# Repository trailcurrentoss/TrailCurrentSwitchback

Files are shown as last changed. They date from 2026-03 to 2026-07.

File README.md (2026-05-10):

# TrailCurrent Switchback

CAN-controlled 8-channel relay module for the TrailCurrent ecosystem, built on the [Waveshare ESP32-S3-ETH-8DI-8RO-C](https://www.waveshare.com/wiki/ESP32-S3-ETH-8DI-8RO-C).

## Hardware

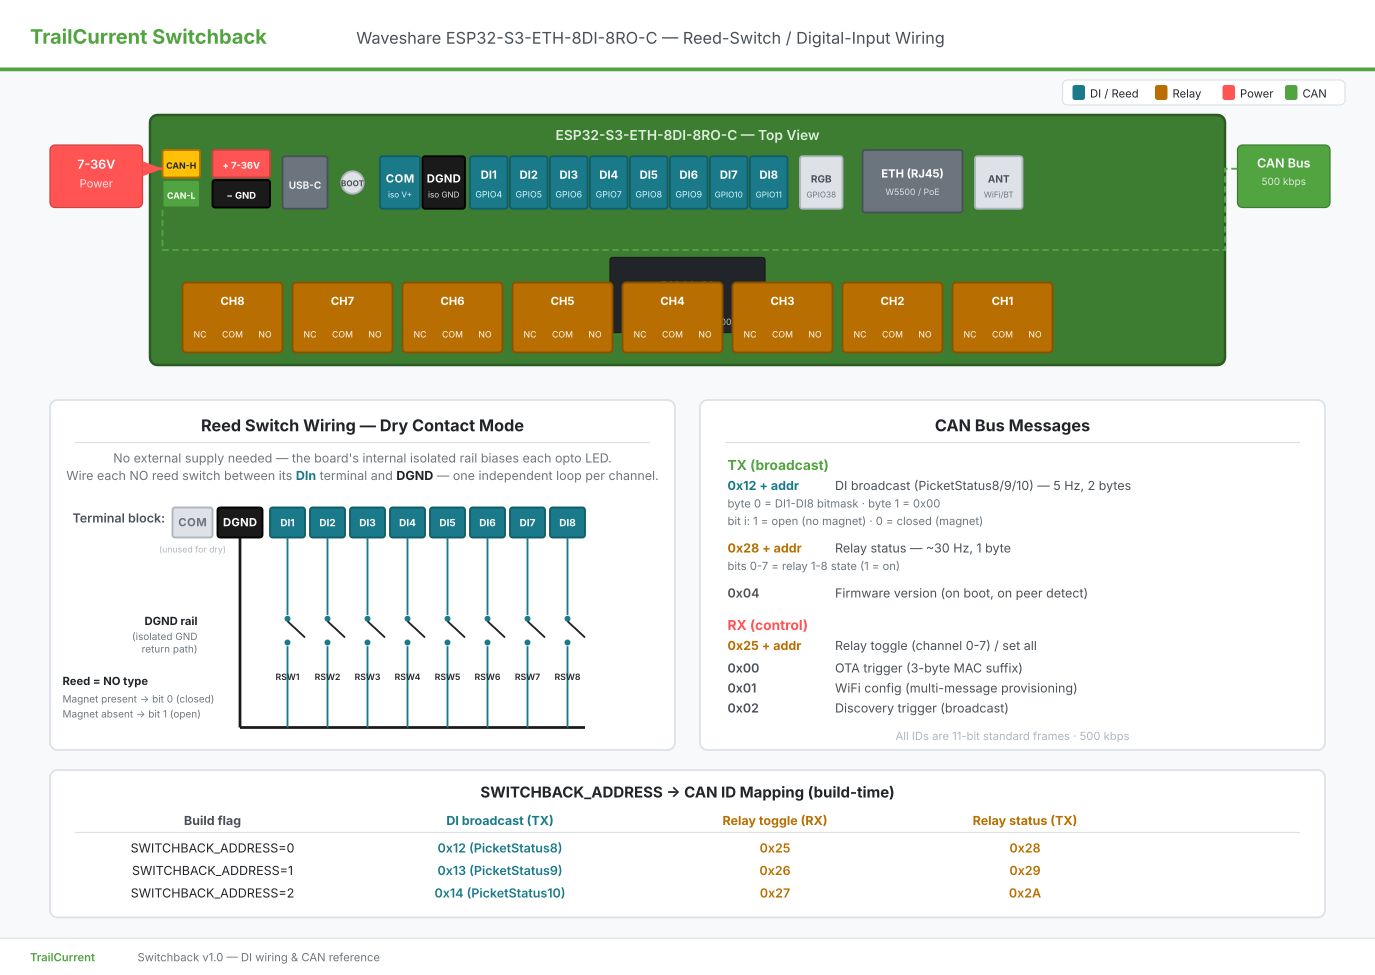
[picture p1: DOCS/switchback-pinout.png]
Switchback pinout and reed switch wiring


For a full design overview see [DOCS/Requirements/high-level-requirements.md](DOCS/Requirements/high-level-requirements.md).

The Waveshare ESP32-S3-ETH-8DI-8RO-C provides:

- **ESP32-S3** dual-core LX7 @ 240 MHz with WiFi and BLE
- **8 relay channels** (1NO/1NC each), rated 10A @ 250V AC / 10A @ 30V DC, via TCA9554PWR I2C I/O expander
- **8 digital inputs** (optocoupler isolated)
- **CAN bus** with onboard transceiver and 120 ohm termination jumper
- **Ethernet** (W5500 via SPI, 10/100 Mbps)
- **7-36V DC** input (or 5V via USB-C)
- **RTC** (PCF85063ATL) with battery backup header
- **SD card** slot (MMC 1-bit mode)
- DIN-rail mount enclosure

## Firmware

### Pin Assignments

Relays are controlled via TCA9554PWR I2C I/O expander (address 0x20) on I2C SDA=GPIO42, SCL=GPIO41.

| Function | Pin / Address |
|---|---|
| Relay 1-8  | TCA9554 P0-P7 (I2C 0x20) |
| DI 1-8 | GPIO 4-11 |
| CAN TX | GPIO 17 |
| CAN RX | GPIO 18 |
| Buzzer | GPIO 46 |
| RGB LED | GPIO 38 |
| ETH MOSI | GPIO 13 |
| ETH MISO | GPIO 14 |
| ETH SCLK | GPIO 15 |
| ETH CS | GPIO 16 |

### CAN Protocol

CAN bus runs at **500 kbps** in no-ACK mode.

| CAN ID | Direction | Description |
|---|---|---|
| `0x00` | RX | **OTA trigger** — 3-byte payload (MAC bytes 3-5) targets a specific device |
| `0x01` | RX | **WiFi config** — multi-message chunked protocol to provision SSID and password |
| `0x12 + addr` | TX | **Digital input broadcast** — 2-byte Picket-format frame (byte 0 = DI1-DI8 bitmask, byte 1 = 0x00), 5 Hz. Identical wire format to `PicketStatus0..7`, so Headwaters decodes it through the same path. |
| `0x25 + addr` | RX | **Relay toggle** — toggle a single relay (channel 0-7) or set all relays (channel >= 8, byte 2 = on/off) |
| `0x28 + addr` | TX | **Relay status broadcast** — 1-byte bitmask (bits 0-7 = relay states), sent at ~30 Hz |

Up to 3 Switchback modules can share the same CAN bus. CAN IDs are offset by the `SWITCHBACK_ADDRESS` build flag:

| Base ID | Addr 0 | Addr 1 | Addr 2 | Description |
|---|---|---|---|---|
| 0x12 | 0x12 | 0x13 | 0x14 | Digital input broadcast (TX) — `PicketStatus8/9/10` |
| 0x25 | 0x25 | 0x26 | 0x27 | Relay toggle (RX) |
| 0x28 | 0x28 | 0x29 | 0x2A | Relay status broadcast (TX) |

The DI broadcast (CAN ID `0x12 + addr`) reuses the **Picket** message format byte-for-byte: byte 0 carries DI1-DI8 (`1` = open / no current through optocoupler, `0` = closed); byte 1 is always `0x00` (Picket uses it for inputs 9-12, which Switchback hardware doesn't expose). Inputs are debounced for 50 ms and the frame is sent at 5 Hz, matching Picket exactly. For dry-contact wiring, connect each NO reed switch between its `DIn` terminal and `DGND` — the board's internal isolated rail biases the optocoupler LEDs, so no external supply is needed. See [DOCS/switchback-pinout.png](DOCS/switchback-pinout.png) for the full wiring diagram.

### WiFi Provisioning over CAN

WiFi credentials can be sent to the device over the CAN bus using a multi-message protocol on CAN ID `0x01`:

1. **Start** (type `0x01`) — declares SSID length, password length, chunk counts, and checksum
2. **SSID chunks** (type `0x02`) — up to 6 bytes per message, indexed
3. **Password chunks** (type `0x03`) — up to 6 bytes per message, indexed
4. **End** (type `0x04`) — verifies XOR checksum and saves credentials to NVS

A 5-second timeout resets the state if the sequence is not completed.

### OTA Updates

The firmware supports over-the-air updates via WiFi. An OTA trigger message on CAN ID `0x00` with the device's MAC address (bytes 3-5) puts the device into OTA mode. The flash partition table supports dual-OTA (app0/app1) for safe rollback.

Always use the app-only binary (`switchback_addr{N}.bin`) for OTA, never the merged binary. The merged binary starts with the bootloader, not an app header, and would fail the `esp_ota_end` validation.

```bash
curl -X POST http://esp32-XXYYZZ.local/ota --data-binary @build/switchback_addr0.bin
```

## Building

### Prerequisites

- [ESP-IDF](https://docs.espressif.com/projects/esp-idf/en/stable/esp32s3/get-started/) v5.x

### Build and Flash

```bash
idf.py set-target esp32s3
idf.py build
idf.py -p /dev/ttyACM0 flash monitor
```

### Multi-Instance Addressing

Up to 3 Switchback modules can share the same CAN bus. Each module is built with a unique address:

```bash
idf.py build                        # Address 0 (default)
idf.py build -DSWITCHBACK_ADDRESS=1  # Address 1
idf.py build -DSWITCHBACK_ADDRESS=2  # Address 2
```

#### Building All Variants

Use `build-all.sh` to build all 3 address variants in a single run:

```bash
./build-all.sh
```

This produces two binaries per address — one for OTA updates, one for the web flasher:

| File | Contents | Used By |
|---|---|---|
| `build/switchback_addr{N}.bin` | Application image only | Headwaters OTA (`deploy.sh`, `ota.js`), direct `curl` uploads |
| `build/switchback_addr{N}_merged.bin` | Bootloader + partition table + OTA data + application | Web flasher (full flash at 0x0) |

The two binary types exist because OTA and the web flasher write to different targets. Headwaters OTA sends the binary to the device's `/ota` HTTP endpoint, which calls `esp_ota_write` to write it to a single app partition. That function validates the image as an application — a merged binary starts with the bootloader instead of an app header, so it would fail validation. The web flasher writes the entire flash contents starting at offset 0x0, so it needs all partitions combined into one file.

#### Creating a GitHub Release

After building all variants, attach all 6 binaries (3 app-only + 3 merged) as release assets:

```bash
git tag -a v1.0.0 -m "Firmware release v1.0.0"
git push origin v1.0.0

gh release create v1.0.0 \
  build/switchback_addr0.bin \
  build/switchback_addr1.bin \
  build/switchback_addr2.bin \
  build/switchback_addr0_merged.bin \
  build/switchback_addr1_merged.bin \
  build/switchback_addr2_merged.bin \
  --repo trailcurrentoss/TrailCurrentSwitchback \
  --title "v1.0.0" \
  --notes "Firmware release v1.0.0"
```

Both the Headwaters deployment system and the web flasher pull from GitHub releases. The web flasher matches `_merged.bin` files by name for full-flash use. The Headwaters deployment system (`fetch-firmware.sh`) downloads the app-only `switchback_addr{N}.bin` files for OTA delivery.

## Project Structure

```
TrailCurrentSwitchback/
├── main/
│   ├── main.c              # Entry point — init and CAN task
│   ├── board.h             # Pin definitions for ESP32-S3-ETH-8DI-8RO-C
│   ├── relay.h / relay.c   # TCA9554 I2C relay driver (8 channels)
│   ├── can_handler.h / .c  # CAN protocol and message handling
│   ├── wifi_config.h / .c  # WiFi credential storage and CAN provisioning
│   ├── discovery.h / .c    # mDNS self-discovery and Headwaters registration
│   └── ota.h / ota.c       # OTA firmware updates via WiFi
├── CMakeLists.txt          # Top-level ESP-IDF project file
├── partitions.csv          # Custom flash partition table (dual OTA)
├── build-all.sh            # Build all 3 address variants (addr 0-2)
└── sdkconfig.defaults      # Default SDK configuration
```

## License

See [LICENSE](LICENSE) for details.

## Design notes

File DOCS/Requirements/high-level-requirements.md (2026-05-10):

# High-Level Design (HLD) Document

## 1. Project Overview

**Project Title:** Switchback Module

**Description:** A microcontroller-based system that controls 8 high-current relay outputs over a CAN bus and reports their state back to the network. Reused as a slimmed-down [Picket](../../../TrailCurrentPicket/README.md) replacement when 8 reed-switch / digital inputs are sufficient — the same physical board exposes 8 optocoupler-isolated digital inputs that broadcast door / cabinet status in the existing PicketStatus wire format.

**Objective:**
To design and implement a reliable, industrial-grade, CAN-controlled relay module for the TrailCurrent vehicle platform that can also subsume the Picket door-sensing role at locations where 8 inputs cover the wiring need, eliminating a separate node, its enclosure, its CAN address, and its quiescent power draw.

---

## 2. Microcontroller Selection

**Selected Microcontroller:**
**ESP32-S3** ([Waveshare ESP32-S3-ETH-8DI-8RO-C](https://www.waveshare.com/wiki/ESP32-S3-ETH-8DI-8RO-C))
[Datasheet](https://www.espressif.com/sites/default/files/documentation/esp32-s3_datasheet_en.pdf)

**Rationale for Selection:**
- Off-the-shelf industrial DIN-rail board with **8 onboard relays** (10 A @ 250 V AC / 30 V DC) driven through a TCA9554PWR I²C expander. No relay driver circuit to design.
- **8 digital inputs with bidirectional optocoupler isolation** and onboard isolated supply rail — supports both dry-contact (reed switches, buttons) and wet-contact (5–36 V sensors) wiring without external components.
- Onboard isolated CAN transceiver, W5500 Ethernet, RTC with battery backup, SD slot, RGB LED, buzzer.
- 7–36 V wide-input buck converter (or 5 V via USB-C) — directly compatible with vehicle 12 V / 24 V systems.
- DIN-rail enclosure ships with the board.
- Same ESP-IDF / ESP32-S3 toolchain shared across Picket, Solstice, and other TrailCurrent modules.

---

## 3. System Requirements

### 3.1 Functional Requirements

| Requirement | Description |
|---|---|
| Relay Control | Receive CAN commands to toggle individual relays (channel 0–7) or set all relays on/off. |
| Relay Status Reporting | Broadcast the current 8-bit relay state on CAN at ~30 Hz. |
| Digital Input Sensing | Read 8 optocoupler-isolated inputs and broadcast their debounced state on CAN at 5 Hz in PicketStatus wire format. |
| Multi-Module Addressing | Up to 3 modules per CAN bus. CAN IDs offset by `SWITCHBACK_ADDRESS` build flag (0–2). |
| OTA Updates | Accept firmware updates over WiFi triggered via CAN ID 0x00. Dual-OTA partition layout for safe rollback. |
| Auto-Discovery | Respond to CAN-broadcast discovery triggers by joining WiFi and advertising over mDNS for Headwaters to register. |
| Bus-Off Recovery | Detect TWAI bus-off, initiate recovery, and resume TX automatically when the bus is healthy. |
| No-Peer Probe Mode | Slow down TX to 0.5 Hz when no CAN peers are detected; resume normal cadence on first ACK / RX. |

### 3.2 Non-Functional Requirements

| Requirement | Description |
|---|---|
| Reliability | System must operate continuously without disruption indefinitely for solar / off-grid installs. |
| CAN Bus Data Usage | Combined relay status (30 Hz, 1 byte) + DI broadcast (5 Hz, 2 bytes) ≈ 47 frame-bytes/s per module — negligible on a 500 kbps bus. |
| Environmental Tolerance | Operate within typical industrial ranges (board-rated -20 °C to +70 °C). |
| Galvanic Isolation | All relay-side and input-side connections must remain optically / power-isolated from the MCU rail. |
| Cost | Use the off-the-shelf board as-is; no custom PCB required. |

---

## 4. System Architecture Overview

### 4.0 External Wiring Reference

Switchback pinout and reed switch wiring

The diagram shows every screw-terminal and connector exposed on the [Waveshare ESP32-S3-ETH-8DI-8RO-C](https://www.waveshare.com/wiki/ESP32-S3-ETH-8DI-8RO-C), the dry-contact reed-switch wiring (no external supply needed — the board's onboard isolated rail provides loop current), and the CAN ID layout for all three `SWITCHBACK_ADDRESS` build values.

### 4.1 Hardware Components

| Component | Description |
|---|---|
| ESP32-S3 (Waveshare ESP32-S3-ETH-8DI-8RO-C) | Main microcontroller with onboard CAN, Ethernet, 8 relays, 8 DIs |
| TCA9554PWR I²C I/O Expander | Drives the 8 relay coils (address 0x20, on internal I²C bus SDA=GPIO42 / SCL=GPIO41) |
| Onboard Optocouplers (input side) | Bidirectional isolation for the 8 digital inputs |
| W5500 Ethernet Controller | SPI-attached, currently unused by firmware (reserved for future expansion) |
| PCF85063ATL RTC | Battery-backed real-time clock (currently unused) |
| Reed Switches / Buttons / Sensors | External — wired to DI terminals via dry- or wet-contact configuration |

### 4.2 Software Components

| Component | Description |
|---|---|
| Main Application (`main.c`) | Boot, peripheral init, task spawning |
| Relay Driver (`relay.c`) | TCA9554 I²C bring-up, per-channel toggle, get-states bitmask |
| CAN Handler (`can_handler.c`) | TWAI driver, RX dispatch, relay-status TX (~30 Hz), DI debounce + DI broadcast (5 Hz) |
| WiFi Config (`wifi_config.c`) | NVS-stored credentials and CAN-based provisioning protocol on ID 0x01 |
| OTA (`ota.c`) | HTTP-based OTA update flow, triggered by CAN ID 0x00 with this module's MAC suffix |
| Discovery (`discovery.c`) | mDNS advertisement + Headwaters confirm-handshake on a one-at-a-time CAN-triggered window |
| CAN Common (`can_common.h`, shared library) | Bus init, alert mask, version-broadcast helper — same module used across all TrailCurrent firmware |

### 4.3 Dual-Role Operation

A single Switchback firmware build runs both functions concurrently. The two roles are independent:

| Role | CAN ID (per `SWITCHBACK_ADDRESS`) | Cadence | Source of Truth |
|---|---|---|---|
| Relay status TX | 0x28 / 0x29 / 0x2A | ~30 Hz | TCA9554 output register cache |
| Relay toggle RX | 0x25 / 0x26 / 0x27 | event-driven | Headwaters / dashboards |
| DI broadcast TX | **0x12 / 0x13 / 0x14** | 5 Hz | 50 ms-debounced GPIO read |

The DI side is a byte-for-byte clone of the Picket message format (1 = open, 0 = closed; debounce window, cadence, and signal layout all identical). It extends the Picket address pool — the canonical DBC name for the new IDs is `PicketStatus8`, `PicketStatus9`, `PicketStatus10`.

---

## 5. Communication Protocol

- **CAN Bus:** 500 kbps, no-ACK mode (TWAI driver in normal mode).
- **Data Format:** See [Switchback README — CAN Protocol](../../README.md#can-protocol) and the canonical [TrailCurrent.dbc](../../../TrailCurrentDocumentation/TrailCurrent.dbc).
- **Transmission Frequency:**
  - Relay status: ~30 Hz (33 ms period) — fast enough that downstream UIs feel responsive after a toggle.
  - DI broadcast: 5 Hz (200 ms period) — matches Picket exactly so the same Headwaters consumer code decodes both.
- **Probe Backoff:** When no peers are observed, both TX paths slow to 0.5 Hz to avoid spamming an empty bus, resuming full rate on first TX_SUCCESS or RX_DATA.

---

## 6. Power Management Strategy

- **Input:** 7–36 V DC via screw terminal (vehicle 12 V or 24 V), or 5 V via USB-C for bench work.
- **Onboard Power:** Built-in MP1605GTF-Z buck converter feeds the ESP32-S3 and isolated rails.
- **Quiescent Draw:** Dominated by the W5500, ESP32 WiFi/BLE radios (idle), and the optocoupler bias current. Significantly lower system draw than running a Switchback + Picket pair at the same location.

---

## 7. Development Tools and Environment

| Tool | Description |
|---|---|
| ESP-IDF | Development framework (v5.x) |
| VS Code | Development IDE |
| Git / GitHub | Source control, releases (binaries attached to tagged releases) |
| TrailCurrentCANLibrary | Shared CAN init / version-broadcast component, pulled in via `EXTRA_COMPONENT_DIRS` |
| Documentation Tools | Markdown, DBC for the canonical CAN signal definitions |

---

## 8. Testing and Validation

| Test Type | Description |
|---|---|
| Unit | Per-module — relay driver, DI read path, CAN message parsing |
| Integration | Full firmware on hardware: relay toggle round-trip, DI debounce timing, dual-role TX coexistence |
| Field | Multi-module bus with mixed Picket + Switchback nodes; verify Headwaters decodes 0x0A–0x14 uniformly |
| OTA | Push a new build, verify dual-OTA rollback path on a deliberately corrupt image |

---

## 9. Future Enhancements

- Use the onboard W5500 Ethernet for CAN-over-Ethernet bridging or a direct HTTP control API.
- Wire the RTC to provide a network-independent timestamp for input transitions.
- Add SD-card logging of input-edge events for forensic / diagnostic recall.
- Per-channel relay current sensing (would require an external module — not on this board).

---

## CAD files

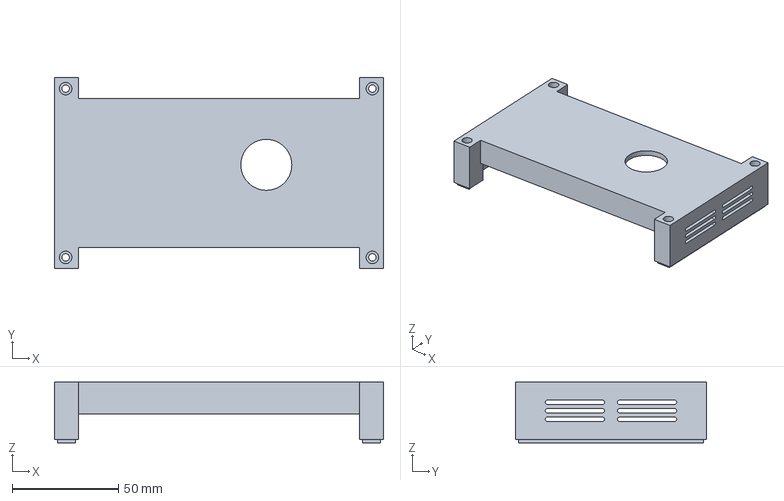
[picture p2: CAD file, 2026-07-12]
CAD/WaveshareCoverWithBorealisAndBearing.FCStd
155.0 x 90.0 x 28.6 mm

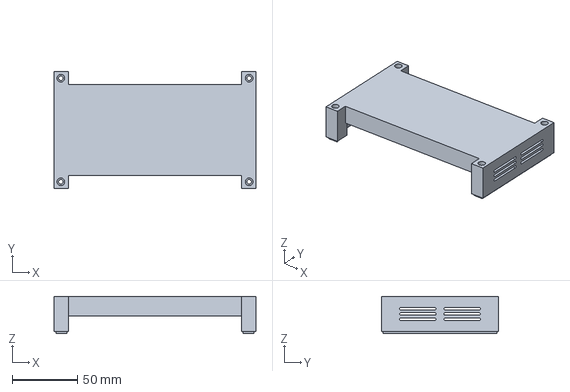
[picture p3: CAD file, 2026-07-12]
CAD/WaveshareCover.FCStd
155.0 x 90.0 x 28.6 mm

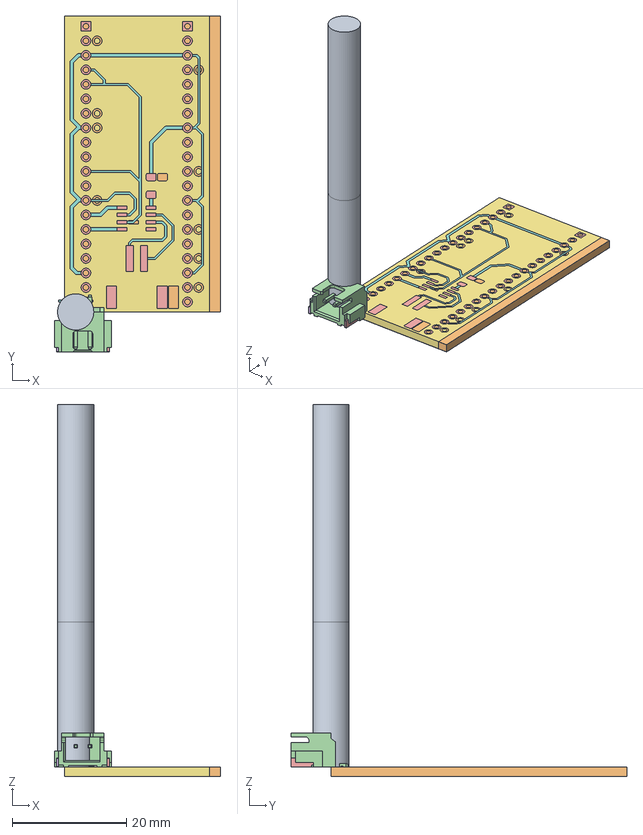
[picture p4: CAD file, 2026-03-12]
CAD/TrailCurrentSwitchbackPcb.FCStd
29.2 x 58.8 x 65.1 mm
Model-TrailCurrentSwitchback
Model-TrailCurrentSwitchback001
BODY-SO
LEAD-D0008A
LEAD-D0008A001
LEAD-D0008A002
LEAD-D0008A003
LEAD-D0008A004
LEAD-D0008A005
LEAD-D0008A006
LEAD-D0008A007
SxB-XH-SM4-TB
SxB-XH-SM4-TB001
SxB-XH-SM4-TB002
Pcb_5bca
topTracks_5bca
SpeTool O Flute 1/4"
Stock009
Stock010
1mm Drill
topPads_5bca
botPads_5bca
botZones_5bca

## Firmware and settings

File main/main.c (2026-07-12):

#include "board.h"
#include "relay.h"
#include "can_handler.h"
#include "wifi_config.h"
#include "discovery.h"
#include "ota.h"
#include "esp_log.h"
#include "driver/gpio.h"
#include "freertos/FreeRTOS.h"
#include "freertos/task.h"
#ifdef SWITCHBACK_VARIANT_GNSS
#include "gnss.h"
#endif
#ifdef SWITCHBACK_VARIANT_SCD41
#include "sensors.h"
#endif

#ifndef SWITCHBACK_ADDRESS
#define SWITCHBACK_ADDRESS 0
#endif

static const char *TAG = "main";

#ifdef SWITCHBACK_VARIANT_GNSS
// Bridge from the gnss RX task straight into the CAN handler's snapshot.
// Fires once per NMEA sentence (RMC + GGA at 1 Hz) — no polling.
static void on_gnss_update(const gnss_data_t *data)
{
    can_handler_publish_gnss(data);
}
#endif  // SWITCHBACK_VARIANT_GNSS

#ifdef SWITCHBACK_VARIANT_SCD41
// SCD41 produces a fresh sample every 5 s in periodic mode. Poll a bit
// faster than that so we don't drift and always publish the newest fix
// as soon as data-ready flips.
#define SCD41_POLL_MS  2000

// Track the latest SCD41 fields so the SGP40 measurement can compensate for
// humidity/temp even on ticks where SCD41 didn't produce fresh data.
static float s_last_temp_c = 25.0f;
static float s_last_humidity = -1.0f;

static void scd41_poll_task(void *arg)
{
    while (1) {
        scd41_data_t d = scd41_read();
        if (d.valid) {
            ESP_LOGI("main", "SCD41: %.1f°C / RH %.1f%% / CO2 %u ppm",
                     d.temperature_c, d.humidity, d.co2_ppm);
            s_last_temp_c = d.temperature_c;
            s_last_humidity = d.humidity;
            can_handler_publish_env(&d);
        }

        // SGP40 needs humidity + temperature for compensation; pass the last
        // good SCD41 pair, or use the datasheet defaults (humidity=-1) if
        // SCD41 hasn't published yet.
        sgp40_data_t sgp = sgp40_measure(s_last_humidity, s_last_temp_c);
        if (sgp.valid) {
            ESP_LOGI("main", "SGP40: VOC raw %u index %u",
                     sgp.voc_raw, sgp.voc_index);
            can_handler_publish_voc(&sgp);
        }

        // SEN0466 CO — active-mode sensor updates ~1 Hz internally, so a
        // read each poll cycle always gives the freshest number.
        co_data_t co = co_sen0466_read();
        if (co.valid) {
            ESP_LOGI("main", "SEN0466: CO %.1f ppm", co.ppm);
            can_handler_publish_co(&co);
        }

        vTaskDelay(pdMS_TO_TICKS(SCD41_POLL_MS));
    }
}
#endif  // SWITCHBACK_VARIANT_SCD41

static void init_digital_inputs(void)
{
    gpio_config_t io_conf = {
        .mode = GPIO_MODE_INPUT,
        .pull_up_en = GPIO_PULLUP_ENABLE,
        .pull_down_en = GPIO_PULLDOWN_DISABLE,
        .intr_type = GPIO_INTR_DISABLE,
    };

    for (int i = 0; i < NUM_DIN; i++) {
        io_conf.pin_bit_mask = 1ULL << DIN_PINS[i];
        gpio_config(&io_conf);
    }

    ESP_LOGI(TAG, "8 digital inputs initialized");
}

void app_main(void)
{
    // Quiet the GNSS + RX chatter so the sensor + relay output stays readable.
    // Errors still surface. Raise back to INFO temporarily if debugging GNSS.
    esp_log_level_set("gnss", ESP_LOG_WARN);

    ESP_LOGI(TAG, "=== TrailCurrent Switchback ===");
    ESP_LOGI(TAG, "CAN-Controlled 8-Channel Relay Module");
    ESP_LOGI(TAG, "Board: Waveshare ESP32-S3-ETH-8DI-8RO-C");

    // Initialize NVS and load WiFi credentials
    ESP_ERROR_CHECK(wifi_config_init());

    char ssid[33] = {0};
    char password[64] = {0};
    if (wifi_config_load(ssid, sizeof(ssid), password, sizeof(password))) {
        ESP_LOGI(TAG, "WiFi credentials loaded from NVS");
    } else {
        ESP_LOGI(TAG, "No WiFi credentials — OTA disabled until provisioned via CAN");
    }

    // Initialize relay outputs via TCA9554 I2C expander
    ESP_ERROR_CHECK(relay_init());

    // Initialize digital inputs
    init_digital_inputs();

    // Initialize discovery and OTA (must be after wifi_config_init)
    discovery_init();
    ota_init();

#if defined(SWITCHBACK_VARIANT_AFTLINE)
    ESP_LOGI(TAG, "Switchback+Aftline addr=%d (Toggle 0x%02X, Status 0x%02X, TrailerStatus 0x3A)",
             SWITCHBACK_ADDRESS,
             CAN_ID_TOGGLE_BASE + SWITCHBACK_ADDRESS,
             CAN_ID_STATUS_BASE + SWITCHBACK_ADDRESS);
#elif defined(SWITCHBACK_VARIANT_PICKET) && defined(SWITCHBACK_VARIANT_GNSS)
    ESP_LOGI(TAG, "Switchback+Picket+GNSS+Env+Safety addr=%d (Toggle 0x%02X, Status 0x%02X, Input 0x%02X, GNSS 0x06-0x09, Env 0x1F, Safety 0x20)",
             SWITCHBACK_ADDRESS,
             CAN_ID_TOGGLE_BASE + SWITCHBACK_ADDRESS,
             CAN_ID_STATUS_BASE + SWITCHBACK_ADDRESS,
             CAN_ID_INPUT_BASE + SWITCHBACK_ADDRESS);
#elif defined(SWITCHBACK_VARIANT_PICKET)
    ESP_LOGI(TAG, "Switchback+Picket addr=%d (Toggle 0x%02X, Status 0x%02X, Input 0x%02X)",
             SWITCHBACK_ADDRESS,
             CAN_ID_TOGGLE_BASE + SWITCHBACK_ADDRESS,
             CAN_ID_STATUS_BASE + SWITCHBACK_ADDRESS,
             CAN_ID_INPUT_BASE + SWITCHBACK_ADDRESS);
#else
    ESP_LOGI(TAG, "Switchback (base) addr=%d (Toggle 0x%02X, Status 0x%02X, no DI broadcast)",
             SWITCHBACK_ADDRESS,
             CAN_ID_TOGGLE_BASE + SWITCHBACK_ADDRESS,
             CAN_ID_STATUS_BASE + SWITCHBACK_ADDRESS);
#endif

    // Initialize CAN bus
    ESP_ERROR_CHECK(can_handler_init());

    // Run CAN handler on a dedicated task
    xTaskCreatePinnedToCore(can_handler_task, "can_task", 4096, NULL, 5, NULL, 1);

#ifdef SWITCHBACK_VARIANT_GNSS
    // DFRobot Gravity GNSS module in UART mode — 9600 baud NMEA. Header pin
    // wiring: D/T (module TX) → ESP RX; C/R (module RX) → ESP TX. UART1 via
    // the GPIO matrix keeps UART0/console untouched.
    ESP_ERROR_CHECK(gnss_init(SWITCHBACK_GNSS_UART_NUM,
                              SWITCHBACK_GNSS_UART_TX,
                              SWITCHBACK_GNSS_UART_RX,
                              SWITCHBACK_GNSS_BAUD,
                              on_gnss_update));
#endif

#ifdef SWITCHBACK_VARIANT_SCD41
    // Air-quality sensor bank on the shared I2C bus (same bus as the TCA9554
    // relay expander): SCD41 CO2/T/RH @ 0x62, SGP40 VOC @ 0x59, SEN0466 CO
    // @ 0x74. Attaches whatever's present; missing devices just leave their
    // slice of the CAN broadcast at zero.
    if (sensors_init(relay_get_i2c_bus()) == ESP_OK) {
        scd41_start_periodic();
        co_sen0466_set_active_mode();
        xTaskCreatePinnedToCore(scd41_poll_task, "scd41", 4096, NULL, 3, NULL, 0);
    } else {
        ESP_LOGW(TAG, "Sensor init failed — environmental / safety broadcast disabled");
    }
#endif

    ESP_LOGI(TAG, "=== Setup Complete ===");
}

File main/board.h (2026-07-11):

#pragma once

#include "driver/gpio.h"
#include "driver/i2c_master.h"
#include "driver/twai.h"
#include "driver/uart.h"

// --- Waveshare ESP32-S3-ETH-8DI-8RO-C pin assignments ---

// I2C bus (TCA9554PWR relay expander + PCF85063ATL RTC)
#define BOARD_I2C_SDA_PIN       GPIO_NUM_42
#define BOARD_I2C_SCL_PIN       GPIO_NUM_41
#define BOARD_I2C_FREQ_HZ       100000

// TCA9554PWR I/O expander (8 relay outputs)
#define TCA9554_ADDR            0x20
#define TCA9554_REG_INPUT       0x00
#define TCA9554_REG_OUTPUT      0x01
#define TCA9554_REG_POLARITY    0x02
#define TCA9554_REG_CONFIG      0x03

#define NUM_RELAYS              8

// Digital inputs (optocoupler isolated, active-low)
#define DI1_PIN                 GPIO_NUM_4
#define DI2_PIN                 GPIO_NUM_5
#define DI3_PIN                 GPIO_NUM_6
#define DI4_PIN                 GPIO_NUM_7
#define DI5_PIN                 GPIO_NUM_8
#define DI6_PIN                 GPIO_NUM_9
#define DI7_PIN                 GPIO_NUM_10
#define DI8_PIN                 GPIO_NUM_11

#define NUM_DIN                 8

static const gpio_num_t DIN_PINS[NUM_DIN] = {
    DI1_PIN, DI2_PIN, DI3_PIN, DI4_PIN,
    DI5_PIN, DI6_PIN, DI7_PIN, DI8_PIN
};

// CAN bus (TWAI) — shared with RS485, we use CAN mode
#define CAN_TX_PIN              GPIO_NUM_17
#define CAN_RX_PIN              GPIO_NUM_18

// Buzzer (PWM)
#define BUZZER_PIN              GPIO_NUM_46

// WS2812 RGB LED
#define RGB_LED_PIN             GPIO_NUM_38

// Ethernet (W5500 via SPI)
#define ETH_MOSI_PIN            GPIO_NUM_13
#define ETH_MISO_PIN            GPIO_NUM_14
#define ETH_SCLK_PIN            GPIO_NUM_15
#define ETH_CS_PIN              GPIO_NUM_16
#define ETH_INT_PIN             GPIO_NUM_12
#define ETH_RST_PIN             GPIO_NUM_39

// CAN protocol IDs
#define CAN_ID_OTA              0x00
#define CAN_ID_WIFI_CONFIG      0x01
#define CAN_ID_DISCOVERY_TRIGGER 0x02
#define CAN_ID_TOGGLE_BASE      0x25   // + SWITCHBACK_ADDRESS → 0x25-0x27
#define CAN_ID_STATUS_BASE      0x28   // + SWITCHBACK_ADDRESS → 0x28-0x2A
// Reed-switch / digital-input broadcast — Picket-format frame, 5 Hz.
// Lives in the Picket address pool 0x0A-0x14 (Picket fills 0x0A-0x11; Switchback
// extends with addresses 8-10 at 0x12-0x14). Identical 2-byte wire layout, so any
// PicketStatus consumer decodes Switchback DIs without code changes.
#define CAN_ID_INPUT_BASE       0x12   // + SWITCHBACK_ADDRESS → 0x12-0x14

// Bearing-format GNSS broadcast (picket_gnss variant only). Same wire layout
// as standalone Bearing modules, so any GNSS consumer decodes these without
// changes. Do NOT run a picket_gnss Switchback and a standalone Bearing on
// the same CAN bus — both would broadcast the same IDs.
#define CAN_ID_DATETIME         0x06
#define CAN_ID_SAT_SPEED        0x07
#define CAN_ID_ALTITUDE         0x08
#define CAN_ID_LATLON           0x09

// Environmental broadcast (picket_gnss variant only, when SCD41+SGP40 are
// attached). Same wire layout as standalone Borealis EnvironmentalStatus.
// Don't run a picket_gnss Switchback and a standalone Borealis on the same
// bus — both would broadcast 0x1F / 0x20.
#define CAN_ID_ENVIRONMENTAL    0x1F
#define CAN_ID_SAFETY           0x20

// Alarm bitmask packed into the SafetyStatus frame. Matches Borealis so
// existing dashboards decode it unchanged. LPG bits stay zero because
// Switchback carries no MQ-6 propane sensor.
#define ALARM_FLAG_CO_WARN      0x01
#define ALARM_FLAG_CO_ALARM     0x02
#define ALARM_FLAG_LPG_WARN     0x04
#define ALARM_FLAG_LPG_ALARM    0x08
#define ALARM_FLAG_CO2_WARN     0x10
#define ALARM_FLAG_CO2_ALARM    0x20
#define ALARM_FLAG_VOC_ALARM    0x40

// Thresholds — same values Borealis uses so a single dashboard config works
// across every TrailCurrent module.
#define CO_PPM_WARNING          70
#define CO_PPM_ALARM            200
#define CO2_PPM_WARNING         1500
#define CO2_PPM_ALARM           2500
#define VOC_INDEX_ALARM         400

// CAN baud rate
#define CAN_BAUD_RATE           500  // kbps

// --- picket_gnss variant (SWITCHBACK_VARIANT_GNSS defined) ---
// DFRobot Gravity GNSS (TEL0157) via UART1 on the header. Uses DFRobot's
// proprietary register-over-UART protocol (see gnss.c), NOT NMEA — the
// module is silent until commanded.
//
// Wiring (bottom row of the Waveshare internal header, adjacent pins so a
// 2-pin housing fits directly, and neither pin conflicts with anything —
// SD-MMC / ETH / CAN / I2C / RGB / buzzer / RTC / USB are all elsewhere).
//   Header pin labeled "2" (GPIO2, ADC1_CH1) ← module D/T (module TX output)
//   Header pin labeled "1" (GPIO1, ADC1_CH0) → module C/R (module RX input)
//   Any G  → module GND
//   Any 3V3 → module VCC
#ifdef SWITCHBACK_VARIANT_GNSS
#define SWITCHBACK_GNSS_UART_NUM  UART_NUM_1
#define SWITCHBACK_GNSS_UART_TX   GPIO_NUM_1    // ESP32 TX → module C/R (RX)
#define SWITCHBACK_GNSS_UART_RX   GPIO_NUM_2    // ESP32 RX ← module D/T (TX)
#define SWITCHBACK_GNSS_BAUD      9600
#endif
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

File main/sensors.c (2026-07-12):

#include "sensors.h"

// SCD41 support is only compiled into variants that define SWITCHBACK_VARIANT_SCD41
// (currently just picket_gnss). Everything else ships an empty translation unit
// so we don't drag the driver into base/picket/aftline binaries.
#ifdef SWITCHBACK_VARIANT_SCD41

#include <string.h>
#include <math.h>
#include "freertos/FreeRTOS.h"
#include "freertos/task.h"
#include "esp_log.h"

static const char *TAG = "sensors";

static i2c_master_dev_handle_t s_scd41_dev = NULL;
static i2c_master_dev_handle_t s_sgp40_dev = NULL;
static i2c_master_dev_handle_t s_co_dev = NULL;

// SCD41 command opcodes (from Sensirion datasheet)
#define SCD41_CMD_START_PERIODIC  0x21B1
#define SCD41_CMD_READ_MEAS       0xEC05
#define SCD41_CMD_GET_DATA_READY  0xE4B8
#define SCD41_CMD_STOP_PERIODIC   0x3F86

// Sensirion CRC-8 (poly 0x31, init 0xFF). Same primitive SGP40, SHT4x, and
// friends use — kept local so this file has no dependency on the wider
// Borealis sensors module.
static uint8_t sensirion_crc8(const uint8_t *data, size_t len)
{
    uint8_t crc = 0xFF;
    for (size_t i = 0; i < len; i++) {
        crc ^= data[i];
        for (int b = 0; b < 8; b++) {
            crc = (crc & 0x80) ? (crc << 1) ^ 0x31 : (crc << 1);
        }
    }
    return crc;
}

static esp_err_t sensirion_send_cmd(uint16_t cmd)
{
    if (!s_scd41_dev) return ESP_ERR_INVALID_STATE;
    uint8_t buf[2] = { (cmd >> 8) & 0xFF, cmd & 0xFF };
    return i2c_master_transmit(s_scd41_dev, buf, 2, 1000);
}

esp_err_t sensors_init(i2c_master_bus_handle_t bus)
{
    if (!bus) {
        ESP_LOGE(TAG, "sensors_init called with NULL bus (relay_init must run first)");
        return ESP_ERR_INVALID_ARG;
    }
    if (s_scd41_dev) { i2c_master_bus_rm_device(s_scd41_dev); s_scd41_dev = NULL; }
    if (s_sgp40_dev) { i2c_master_bus_rm_device(s_sgp40_dev); s_sgp40_dev = NULL; }
    if (s_co_dev)    { i2c_master_bus_rm_device(s_co_dev);    s_co_dev = NULL; }

    i2c_device_config_t scd41_cfg = {
        .dev_addr_length = I2C_ADDR_BIT_LEN_7,
        .device_address = SCD41_I2C_ADDR,
        .scl_speed_hz = 100000,
    };
    if (i2c_master_bus_add_device(bus, &scd41_cfg, &s_scd41_dev) != ESP_OK) {
        ESP_LOGE(TAG, "SCD41 attach failed");
        s_scd41_dev = NULL;
    } else {
        ESP_LOGI(TAG, "SCD41 attached (0x%02X)", SCD41_I2C_ADDR);
    }

    i2c_device_config_t sgp40_cfg = {
        .dev_addr_length = I2C_ADDR_BIT_LEN_7,
        .device_address = SGP40_I2C_ADDR,
        .scl_speed_hz = 100000,
    };
    if (i2c_master_bus_add_device(bus, &sgp40_cfg, &s_sgp40_dev) != ESP_OK) {
        ESP_LOGE(TAG, "SGP40 attach failed");
        s_sgp40_dev = NULL;
    } else {
        ESP_LOGI(TAG, "SGP40 attached (0x%02X)", SGP40_I2C_ADDR);
    }

    i2c_device_config_t co_cfg = {
        .dev_addr_length = I2C_ADDR_BIT_LEN_7,
        .device_address = SEN0466_I2C_ADDR,
        .scl_speed_hz = 100000,
    };
    if (i2c_master_bus_add_device(bus, &co_cfg, &s_co_dev) != ESP_OK) {
        ESP_LOGE(TAG, "SEN0466 attach failed");
        s_co_dev = NULL;
    } else {
        ESP_LOGI(TAG, "SEN0466 CO sensor attached (0x%02X)", SEN0466_I2C_ADDR);
    }

    // Non-fatal on individual device miss — any surviving sensor keeps
    // contributing to its slice of the CAN broadcasts.
    return (s_scd41_dev || s_sgp40_dev || s_co_dev) ? ESP_OK : ESP_ERR_NOT_FOUND;
}

esp_err_t scd41_start_periodic(void)
{
    esp_err_t err = sensirion_send_cmd(SCD41_CMD_START_PERIODIC);
    if (err != ESP_OK) {
        ESP_LOGE(TAG, "SCD41 start_periodic failed: %s", esp_err_to_name(err));
    } else {
        ESP_LOGI(TAG, "SCD41 periodic measurement started (5s update cadence)");
    }
    return err;
}

static bool scd41_data_ready(void)
{
    if (sensirion_send_cmd(SCD41_CMD_GET_DATA_READY) != ESP_OK) return false;
    vTaskDelay(pdMS_TO_TICKS(2));
    uint8_t resp[3];
    if (i2c_master_receive(s_scd41_dev, resp, 3, 1000) != ESP_OK) return false;
    if (sensirion_crc8(resp, 2) != resp[2]) return false;
    uint16_t status = ((uint16_t)resp[0] << 8) | resp[1];
    // Lower 11 bits == 0 means no data available yet
    return (status & 0x07FF) != 0;
}

scd41_data_t scd41_read(void)
{
    scd41_data_t out = { .valid = false };
    if (!s_scd41_dev) return out;
    if (!scd41_data_ready()) return out;

    if (sensirion_send_cmd(SCD41_CMD_READ_MEAS) != ESP_OK) return out;
    vTaskDelay(pdMS_TO_TICKS(2));

    uint8_t buf[9];
    if (i2c_master_receive(s_scd41_dev, buf, sizeof(buf), 1000) != ESP_OK) return out;

    if (sensirion_crc8(&buf[0], 2) != buf[2] ||
        sensirion_crc8(&buf[3], 2) != buf[5] ||
        sensirion_crc8(&buf[6], 2) != buf[8]) {
        ESP_LOGW(TAG, "SCD41 CRC error");
        return out;
    }

    uint16_t raw_co2 = ((uint16_t)buf[0] << 8) | buf[1];
    uint16_t raw_t   = ((uint16_t)buf[3] << 8) | buf[4];
    uint16_t raw_rh  = ((uint16_t)buf[6] << 8) | buf[7];

    out.co2_ppm       = raw_co2;
    out.temperature_c = -45.0f + 175.0f * ((float)raw_t / 65535.0f);
    out.humidity      = 100.0f * ((float)raw_rh / 65535.0f);
    out.valid = true;
    return out;
}

// ---------------------------------------------------------------------------
// SGP40 — Sensirion VOC sensor (raw signal + simple index estimator)
// ---------------------------------------------------------------------------

#define SGP40_CMD_MEASURE_RAW  0x260F

// Same simple estimator Borealis uses. Not the full Sensirion gas_index_algorithm
// (BSD-3, drop-in via component manager) — this is a running-baseline EMA that
// tracks "is air quality changing" without needing 24 h of warm-up. Replace when
// long-term stability matters.
static uint16_t s_sgp40_baseline = 30000;
static bool     s_sgp40_baseline_seeded = false;

static uint16_t sgp40_estimate_index(uint16_t sraw)
{
    if (!s_sgp40_baseline_seeded) {
        s_sgp40_baseline = sraw;
        s_sgp40_baseline_seeded = true;
    }
    // 1/4096 step ≈ 17 minute time constant at 1 Hz sampling.
    int32_t delta_b = (int32_t)sraw - (int32_t)s_sgp40_baseline;
    s_sgp40_baseline = (uint16_t)((int32_t)s_sgp40_baseline + (delta_b / 4096));

    int32_t deviation = (int32_t)sraw - (int32_t)s_sgp40_baseline;
    int32_t idx = 100 + deviation / 50;
    if (idx < 1)   idx = 1;
    if (idx > 500) idx = 500;
    return (uint16_t)idx;
}
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

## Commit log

2026-03-11 Starting project
    [partitions.csv]
2026-03-11 Adding EDA, currently empty will populate for hat soon.
    [TrailCurrentSwitchback.kicad_pcb, TrailCurrentSwitchback.kicad_sch]
2026-03-11 EDA for CAN Hat for waveshare relay and cad for milling pcb edges and drilling holes on Genmitsu 3030
    [TrailCurrentSwitchback.kicad_pcb, TrailCurrentSwitchback.kicad_sch, TrailCurrentSwitchbackPcb.FCStd]
2026-03-11 Updated EDA for professional assembly. Gerber files added ordered 1.0.0 version of the PCB for testing.
    [TrailCurrentSwitchback-B_Cu.gbr, TrailCurrentSwitchback-B_Mask.gbr, TrailCurrentSwitchback-B_Paste.gbr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]
2026-03-12 Updates to CAD for paths
    [TrailCurrentSwitchbackPcb.FCStd]
2026-03-26 Migrated to ESP-IDF
    [TrailCurrentSwitchback-B_Cu.gbr, TrailCurrentSwitchback-B_Mask.gbr, TrailCurrentSwitchback-B_Paste.gbr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]
2026-03-28 Fixed bug where discovery would disrupt CAN messaging
    [discovery.c]
2026-03-28 Implement OTA firmware update via HTTP POST /ota endpoint
    Replace stubbed OTA trigger handler with full implementation matching
    sibling projects. Device enters OTA mode on CAN ID 0x00, connects WiFi,
    exposes HTTP server for firmware upload, and reboots on success.
    Includes mutual exclusion with discovery mode.
    [can_handler.c, discovery.c, main.c]
2026-03-28 Fixing issue with CAN Bus stops responding when discovery happens
    [main.c]
2026-04-09 Updated to build all address combinations for switchback
2026-04-09 Fixes for I2C timeouts
    [relay.c]
2026-04-15 Fixing flash and psram sizes
    [partitions.csv]
2026-05-10 Added picket messaging using the Digital inputs of the waveshare device
2026-06-21 Added logging for picket states and fixed flash issue with build-all
    [can_handler.c]
2026-07-11 Added option for bearing to be included
2026-07-11 Adding Borealis capabilities to switchback
    [WaveshareCover.FCStd]
2026-07-12 Fixes for air quality and work started on custom cover for Waveshare ESP32S3 8CH Relay
    [WaveshareCover.FCStd, WaveshareCoverWithBorealisAndBearing.FCStd]
